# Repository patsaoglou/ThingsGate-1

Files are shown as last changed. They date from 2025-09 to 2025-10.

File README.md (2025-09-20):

#   ThingsGate-1

Gateway Motherboard powered by the ThingsCore-1 SOM. Featuring a LTE Modem, a LoraWAN Concentrator, PoE, battery power and solar charging, it is capable of supporting off-grid IoT applications.

#   Realistic View (Comming Soon...)

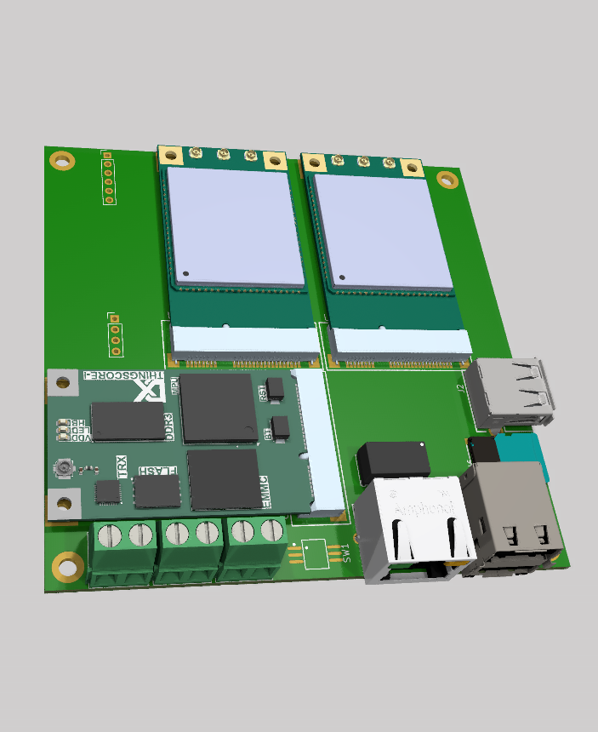
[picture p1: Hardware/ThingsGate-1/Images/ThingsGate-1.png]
Diagram


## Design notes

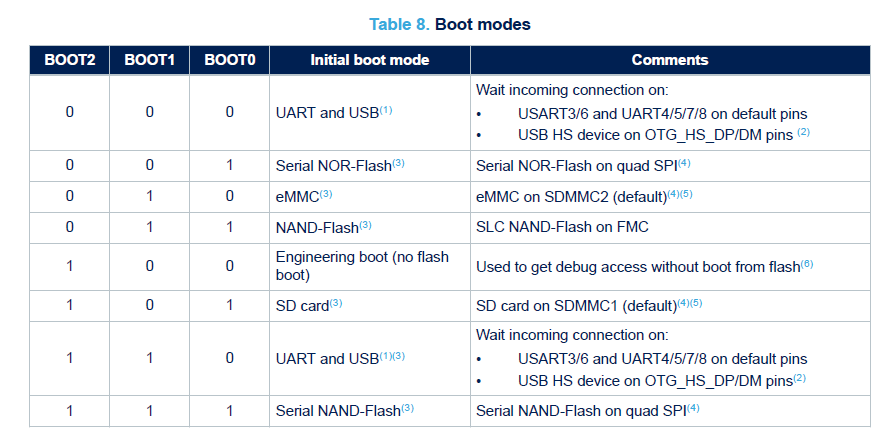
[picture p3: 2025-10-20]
Documentation/BOOTSELECTION .PNG

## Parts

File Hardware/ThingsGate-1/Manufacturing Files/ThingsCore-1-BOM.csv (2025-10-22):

Reference | Qty | Value | DNP | Footprint
BT1 | 1 | S8411-45R |  | ThingsGate-1:Battery_Holder_CR1220_S8411-45R
C1,C2,C3,C4,C5,C6,C13,C20,C21,C24,C25,C26,C32,C36,C38,C39,C40,C41,C42,C43,C44,C45,C49,C52,C54 | 25 | 100n |  | Capacitor_SMD:C_0603_1608Metric
C7 | 1 | 1n |  | Capacitor_SMD:C_1206_3216Metric
C8,C31,C51,C58 | 4 | 10u |  | Fuse:Fuse_0805_2012Metric
C9,C10 | 2 | 330uF 50V |  | Capacitor_SMD:CP_Elec_10x10.5
C11,C12 | 2 | 10u |  | Capacitor_SMD:C_0805_2012Metric
C14,C15 | 2 | 47u |  | Capacitor_SMD:C_0805_2012Metric
C16 | 1 | 1n |  | Capacitor_SMD:C_0603_1608Metric
C17 | 1 | 47p |  | Capacitor_SMD:C_0603_1608Metric
C18,C19,C22,C23 | 4 | 4.7u |  | Capacitor_SMD:C_0805_2012Metric
C27 | 1 | 4.7n |  | Capacitor_SMD:C_0603_1608Metric
C28,C55,C56,C57 | 4 | 39p |  | Capacitor_SMD:C_0603_1608Metric
C29,C30,C46,C47,C48 | 5 | 22u |  | Capacitor_SMD:C_0805_2012Metric
C33,C35,C37,C50,C53 | 5 | 1u |  | Fuse:Fuse_0805_2012Metric
C34 | 1 | 4.7u |  | Fuse:Fuse_0805_2012Metric
D1,D2 | 2 | B360 |  | Diode_SMD:D_SMA
D3,D5,D7 | 3 | SMAJ15CA |  | Diode_SMD:D_SMA
D4,D6 | 2 | BZT52C10 |  | Diode_SMD:D_SOD-123
D8,D9,D10,D11 | 4 | 1N5817WS |  | Diode_SMD:D_SOD-323
D12 | 1 | RED |  | LED_SMD:LED_0603_1608Metric
F1,F2,F3,F4 | 4 | 4A |  | Fuse:Fuse_1206_3216Metric
F5,F6,F7 | 3 | 500mA |  | Fuse:Fuse_1206_3216Metric
J1 | 1 | Conn_02x07_Odd_Even |  | Connector_IDC:IDC-Header_2x07_P2.54mm_Vertical
J3,J4,J6 | 3 | 691313710002 |  | ThingsGate-1:691313710002
J5 | 1 | USB_A_Stacked |  | ThingsGate-1:DUAL_USB-TYPE_A
J7 | 1 | USB_A |  | ThingsGate-1:USB-A-TH_AF-ZJB13.7
L1,L2,L3 | 3 | 6.8u |  | ThingsGate-1:L_0730-6R8M
L4 | 1 | 2.2u |  | ThingsGate-1:L_0805_2016
Q1,Q3 | 2 | Si4435DDY |  | ThingsGate-1:SO-8_3.9x4.9mm_P1.27mm
Q2,Q4,Q5,Q6,Q7 | 5 | Si4178DY |  | ThingsGate-1:SO-8_3.9x4.9mm_P1.27mm
R1,R2,R32,R34,R35,R36,R38,R40 | 8 | 100K |  | Resistor_SMD:R_0603_1608Metric
R3,R4,R5,R6 | 4 | 75R |  | Resistor_SMD:R_0603_1608Metric
R7,R8,R9,R17,R25,R26,R30,R39,R41,R42,R43,R44,R46,R47,R49,R50,R51,R52,R55,R56,R57,R58 | 22 | 10k |  | Resistor_SMD:R_0603_1608Metric
R10 | 1 | 3.24k |  | Resistor_SMD:R_0603_1608Metric
R11 | 1 | 29.4k |  | Resistor_SMD:R_0603_1608Metric
R12,R14 | 2 | 332k |  | Resistor_SMD:R_0603_1608Metric
R13,R15 | 2 | 68.1k |  | Resistor_SMD:R_0603_1608Metric
R16 | 1 | 49.4k |  | Resistor_SMD:R_0603_1608Metric
R18 | 1 | 1.91k |  | Resistor_SMD:R_0603_1608Metric
R19 | 1 | 10R |  | Resistor_SMD:R_1206_3216Metric
R20,R31 | 2 | 0.015R |  | Resistor_SMD:R_1206_3216Metric
R23,R27 | 2 | 100k |  | Resistor_SMD:R_0603_1608Metric
R24 | 1 | 7.15k |  | Resistor_SMD:R_0603_1608Metric
R28 | 1 | 2k |  | Resistor_SMD:R_0603_1608Metric
R29 | 1 | 16k |  | Resistor_SMD:R_0603_1608Metric
R33 | 1 | 5.1K |  | Resistor_SMD:R_0603_1608Metric
R37 | 1 | 10K |  | Resistor_SMD:R_0603_1608Metric
R45 | 1 | 100R |  | Resistor_SMD:R_0603_1608Metric
SW1 | 1 | DSHP03TS-S |  | ThingsGate-1:SW-SMD_DSHP03TS-S
T1 | 1 | H1102NL |  | ThingsGate-1:H1102NL
TP1,TP2,TP3,TP4,TP5,TP6,TP7,TP8 | 8 | TestPoint |  | TestPoint:TestPoint_Pad_D1.5mm
U1 | 1 | CH334R |  | Package_SO:QSOP-16_3.9x4.9mm_P0.635mm
U2 | 1 | ThingsCore-1 |  | ThingsGate-1:ThingsCore-1
U3 | 1 | POE_PD_Module |  | ThingsGate-1:SDAPO_DP9700
U4,U12,U13 | 3 | LM74700 |  | Package_TO_SOT_SMD:SOT-23-6
U5 | 1 | BQ24650 |  | ThingsGate-1:Texas_RVA_VQFN-16-1EP_3.5x3.5mm_P0.5mm_EP2.14x2.14mm_ThermalVias
U6 | 1 | TCA9535PWR |  | Package_SO:SSOP-24_5.3x8.2mm_P0.65mm
U7,U8 | 2 | mPCIE-52P-SLOT |  | ThingsGate-1:mpcie-slot_full
U9,U10 | 2 | TPS54331DR |  | ThingsGate-1:TPS54331DDAR_PowerPAD
U11 | 1 | RJ45-202-007-02 |  | ThingsGate-1:RJ45-TH_RJ45-202-007-02
U14 | 1 | LM324 |  | Package_SO:SOIC-14_3.9x8.7mm_P1.27mm
U15 | 1 | TF-123B-ARP9H17 |  | ThingsGate-1:TF-SMD_TF-123-ARP9H15
U16 | 1 | SMN-305-ARP7 |  | ThingsGate-1:NANO-SIM-SMD_SMN-305-ARP7
U17,U18 | 2 | PC817 |  | Package_DIP:DIP-4_W7.62mm_SMDSocket_SmallPads
Y1 | 1 | X322512MOB4SI |  | Crystal:Crystal_SMD_3225-4Pin_3.2x2.5mm

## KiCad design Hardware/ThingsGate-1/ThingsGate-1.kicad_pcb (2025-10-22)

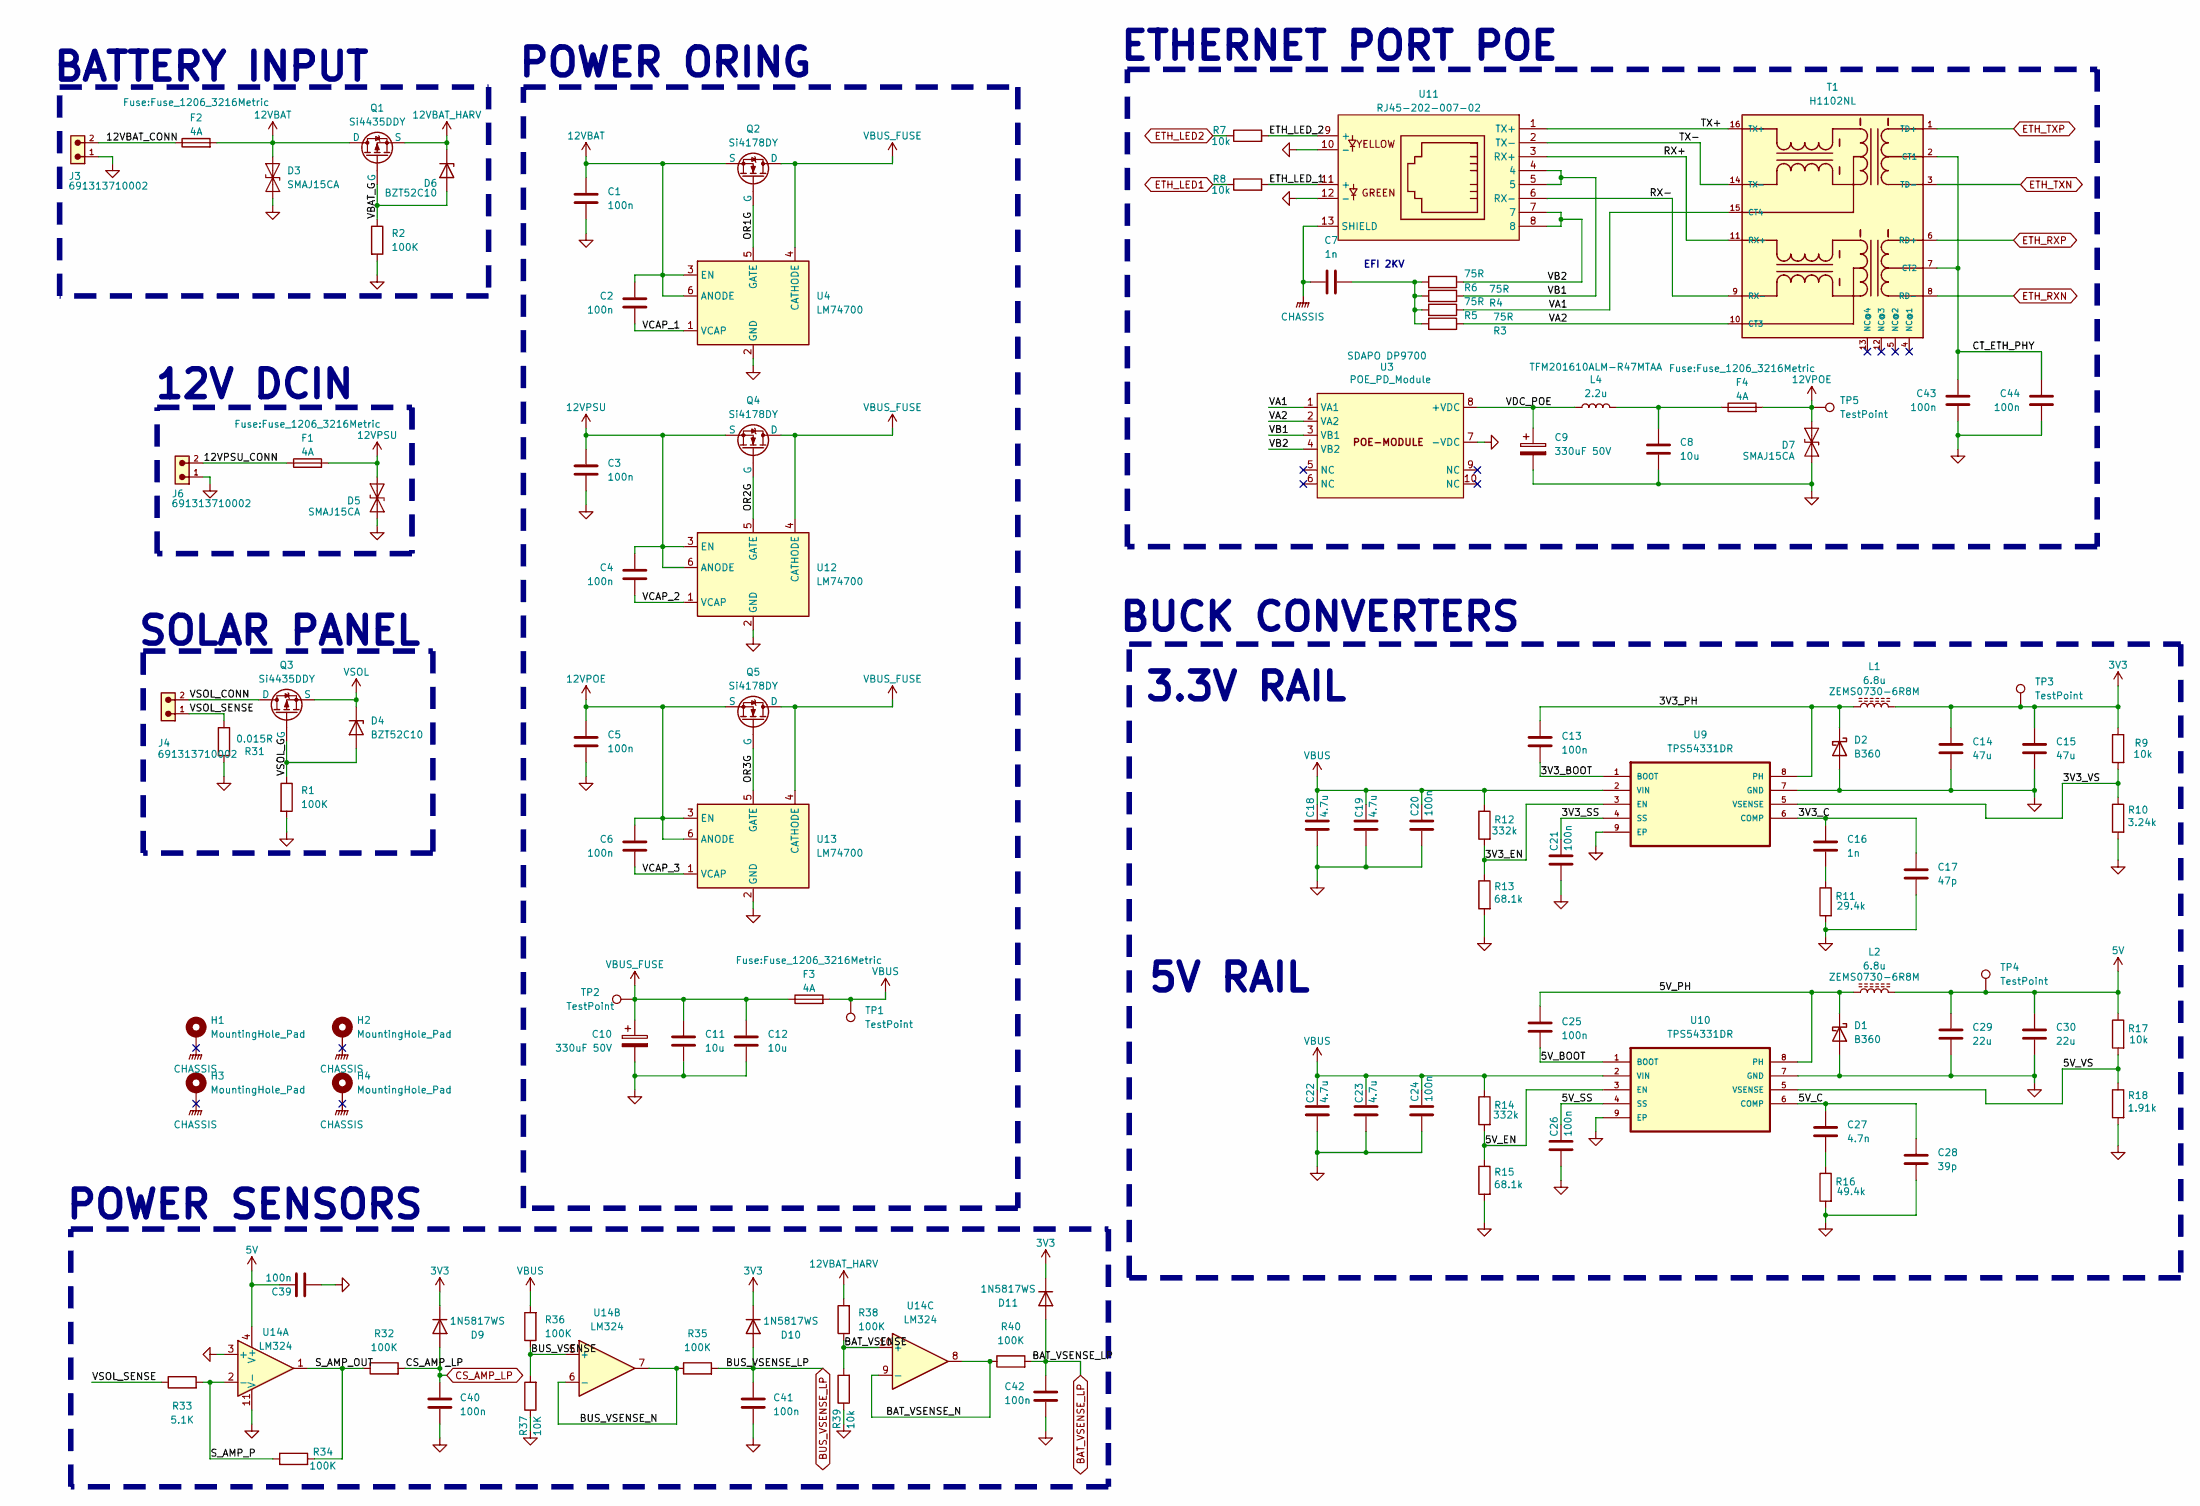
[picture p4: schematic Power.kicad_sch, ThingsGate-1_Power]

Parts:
C1, C2, C3, C4, C5, C6, C13, C20, C21, C24, C25, C26, C39, C40, C41, C42, C43, C44: 100n; C_0603_1608Metric
C7: 1n; C_1206_3216Metric
C8: 10u; Fuse_0805_2012Metric
C9, C10: 330uF 50V; CP_Elec_10x10.5
C11, C12: 10u; C_0805_2012Metric
C14, C15: 47u; C_0805_2012Metric
C16: 1n; C_0603_1608Metric
C17: 47p; C_0603_1608Metric
C18, C19, C22, C23: 4.7u; C_0805_2012Metric
C27: 4.7n; C_0603_1608Metric
C28: 39p; C_0603_1608Metric
C29, C30: 22u; C_0805_2012Metric
D1, D2: B360; D_SMA
D3, D5, D7: SMAJ15CA; D_SMA
D4, D6: BZT52C10; D_SOD-123
D9, D10, D11: 1N5817WS; D_SOD-323
F1, F2, F3, F4: 4A; Fuse_1206_3216Metric
H1, H2, H3, H4: MountingHole_Pad; MountingHole_3.2mm_M3_DIN965_Pad_TopBottom
J3, J4, J6: 691313710002
L1, L2: 6.8u; L_0730-6R8M
L4: 2.2u; L_0805_2016
Q1, Q3: Si4435DDY; SO-8_3.9x4.9mm_P1.27mm
Q2, Q4, Q5: Si4178DY; SO-8_3.9x4.9mm_P1.27mm
R1, R2, R32, R34, R35, R36, R38, R40: 100K; R_0603_1608Metric
R3, R4, R5, R6: 75R; R_0603_1608Metric
R7, R8, R9, R17, R39: 10k; R_0603_1608Metric
R10: 3.24k; R_0603_1608Metric
R11: 29.4k; R_0603_1608Metric
R12, R14: 332k; R_0603_1608Metric
R13, R15: 68.1k; R_0603_1608Metric
R16: 49.4k; R_0603_1608Metric
R18: 1.91k; R_0603_1608Metric
R31: 0.015R; R_1206_3216Metric
R33: 5.1K; R_0603_1608Metric
R37: 10K; R_0603_1608Metric
T1: H1102NL
TP1, TP2, TP3, TP4, TP5: TestPoint; TestPoint_Pad_D1.5mm
U3: POE_PD_Module; SDAPO_DP9700; Part SDAPO DP9700
U4, U12, U13: LM74700; SOT-23-6
U9, U10: TPS54331DR; TPS54331DDAR_PowerPAD
U11: RJ45-202-007-02; RJ45-TH_RJ45-202-007-02
U14: LM324; SOIC-14_3.9x8.7mm_P1.27mm

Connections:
3V3: C14.1, C15.1, D9.1 (K), D10.1 (K), D11.1 (K), L1.2, R9.1, TP3.1; also elsewhere on the board
5V: C29.1, C30.1, C39.1, L2.2, R17.1, TP4.1, U14.4 (V+); also elsewhere on the board
12VBAT: C1.1, C2.1, D3.2 (A2), F2.2, Q1.5 (D), Q1.6 (D), Q1.7 (D), Q1.8 (D), Q2.1 (S), Q2.2 (S), Q2.3 (S), U4.3 (EN), U4.6 (ANODE)
12VBAT_HARV: D6.1 (K), Q1.1 (S), Q1.2 (S), Q1.3 (S), R38.2; also elsewhere on the board
12VPOE: C5.1, C6.1, D7.2 (A2), F4.2, Q5.1 (S), Q5.2 (S), Q5.3 (S), TP5.1, U13.3 (EN), U13.6 (ANODE)
12VPSU: C3.1, C4.1, D5.2 (A2), F1.2, Q4.1 (S), Q4.2 (S), Q4.3 (S), U12.3 (EN), U12.6 (ANODE)
/Power Supply/3V3_BOOT: C13.2, U9.1 (BOOT)
/Power Supply/3V3_C: C16.1, C17.1, U9.6 (COMP)
/Power Supply/3V3_EN: R12.2, R13.1, U9.3 (EN)
/Power Supply/3V3_PH: C13.1, D2.1 (K), L1.1, U9.8 (PH)
/Power Supply/3V3_SS: C21.1, U9.4 (SS)
/Power Supply/3V3_VS: R9.2, R10.1, U9.5 (VSENSE)
/Power Supply/5V_BOOT: C25.2, U10.1 (BOOT)
/Power Supply/5V_C: C27.1, C28.1, U10.6 (COMP)
/Power Supply/5V_EN: R14.2, R15.1, U10.3 (EN)
/Power Supply/5V_PH: C25.1, D1.1 (K), L2.1, U10.8 (PH)
/Power Supply/5V_SS: C26.1, U10.4 (SS)
/Power Supply/5V_VS: R17.2, R18.1, U10.5 (VSENSE)
/Power Supply/12VBAT_CONN: F2.1, J3.2
/Power Supply/12VPSU_CONN: F1.1, J6.2
/Power Supply/BAT_VSENSE: R38.1, R39.2, U14.10 (+)
/Power Supply/BAT_VSENSE_N: R40.1, U14.8, U14.9 (-)
/Power Supply/BUS_VSENSE: R36.1, R37.2, U14.5 (+)
/Power Supply/BUS_VSENSE_N: R35.1, U14.6 (-), U14.7
/Power Supply/CT_ETH_PHY: C43.1, C44.1, T1.2 (CT1), T1.7 (CT2)
/Power Supply/ETH_LED_1: R8.2, U11.11 (+)
/Power Supply/ETH_LED_2: R7.2, U11.9 (+)
/Power Supply/OR1G: Q2.4 (G), U4.5 (GATE)
/Power Supply/OR2G: Q4.4 (G), U12.5 (GATE)
/Power Supply/OR3G: Q5.4 (G), U13.5 (GATE)
/Power Supply/RX+: T1.11 (RX+), U11.3 (RX+)
/Power Supply/RX-: T1.9 (RX-), U11.6 (RX-)
/Power Supply/S_AMP_OUT: R32.1, R34.2, U14.1
/Power Supply/S_AMP_P: R33.2, R34.1, U14.2 (-)
/Power Supply/TX+: T1.16 (TX+), U11.1 (TX+)
/Power Supply/TX-: T1.14 (TX-), U11.2 (TX-)
/Power Supply/VA1: R5.1, T1.15 (CT4), U3.1 (VA1)
/Power Supply/VA2: R3.1, T1.10 (CT3), U3.2 (VA2)
/Power Supply/VB1: R4.1, U3.3 (VB1), U11.4, U11.5
/Power Supply/VB2: R6.1, U3.4 (VB2), U11.7, U11.8
/Power Supply/VBAT_G: D6.2 (A), Q1.4 (G), R2.1
/Power Supply/VCAP_1: C2.2, U4.1 (VCAP)
/Power Supply/VCAP_2: C4.2, U12.1 (VCAP)
/Power Supply/VCAP_3: C6.2, U13.1 (VCAP)
/Power Supply/VDC_POE: C9.1, L4.1, U3.8 (+VDC)
/Power Supply/VSOL_CONN: J4.2, Q3.5 (D), Q3.6 (D), Q3.7 (D), Q3.8 (D)
/Power Supply/VSOL_G: D4.2 (A), Q3.4 (G), R1.1
/Power Supply/VSOL_SENSE: J4.1, R31.1, R33.1
BAT_VSENSE_LP: C42.2, D11.2 (A), R40.2; also elsewhere on the board
BUS_VSENSE_LP: C41.2, D10.2 (A), R35.2; also elsewhere on the board
CHASSIS: C7.1, H1.1, H2.1, H3.1, H4.1, U11.13 (SHIELD); also elsewhere on the board
CS_AMP_LP: C40.2, D9.2 (A), R32.2; also elsewhere on the board
ETH_LED1: R8.1; also elsewhere on the board
ETH_LED2: R7.1; also elsewhere on the board
ETH_RXN: T1.8 (RD-); also elsewhere on the board
ETH_RXP: T1.6 (RD+); also elsewhere on the board
ETH_TXN: T1.3 (TD-); also elsewhere on the board
ETH_TXP: T1.1 (TD+); also elsewhere on the board
GND: C1.2, C3.2, C5.2, C8.2, C9.2, C10.2, C11.2, C12.2, C14.2, C15.2, C17.2, C18.2, C19.2, C20.2, C21.2, C22.2, C23.2, C24.2, C26.2, C28.2, C29.2, C30.2, C39.2, C40.1, C41.1, C42.1, C43.2, C44.2, D1.2 (A), D2.2 (A), D3.1 (A1), D5.1 (A1), D7.1 (A1), J3.1, J6.1, R1.2, R2.2, R10.2, R11.2, R13.2, R15.2, R16.2, R18.2, R31.2, R37.1, R39.1, U3.7 (-VDC), U4.2 (GND), U9.7 (GND), U9.9 (EP), U10.7 (GND), U10.9 (EP), U11.10 (-), U11.12 (-), U12.2 (GND), U13.2 (GND), U14.3 (+), U14.11 (V-); also elsewhere on the board
unnamed: C7.2, R3.2, R4.2, R5.2, R6.2
unnamed: C8.1, F4.1, L4.2
unnamed: C16.2, R11.1
unnamed: C27.2, R16.1
VBUS: C18.1, C19.1, C20.1, C22.1, C23.1, C24.1, F3.2, R12.1, R14.1, R36.2, TP1.1, U9.2 (VIN), U10.2 (VIN)
VBUS_FUSE: C10.1, C11.1, C12.1, F3.1, Q2.5 (D), Q2.6 (D), Q2.7 (D), Q2.8 (D), Q4.5 (D), Q4.6 (D), Q4.7 (D), Q4.8 (D), Q5.5 (D), Q5.6 (D), Q5.7 (D), Q5.8 (D), TP2.1, U4.4 (CATHODE), U12.4 (CATHODE), U13.4 (CATHODE)
VSOL: D4.1 (K), Q3.1 (S), Q3.2 (S), Q3.3 (S); also elsewhere on the board

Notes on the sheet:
BUCK CONVERTERS
ETHERNET PORT POE
BATTERY INPUT
3.3V RAIL
POWER SENSORS
5V RAIL
SOLAR PANEL
EFI 2KV
12V DCIN
POWER ORING

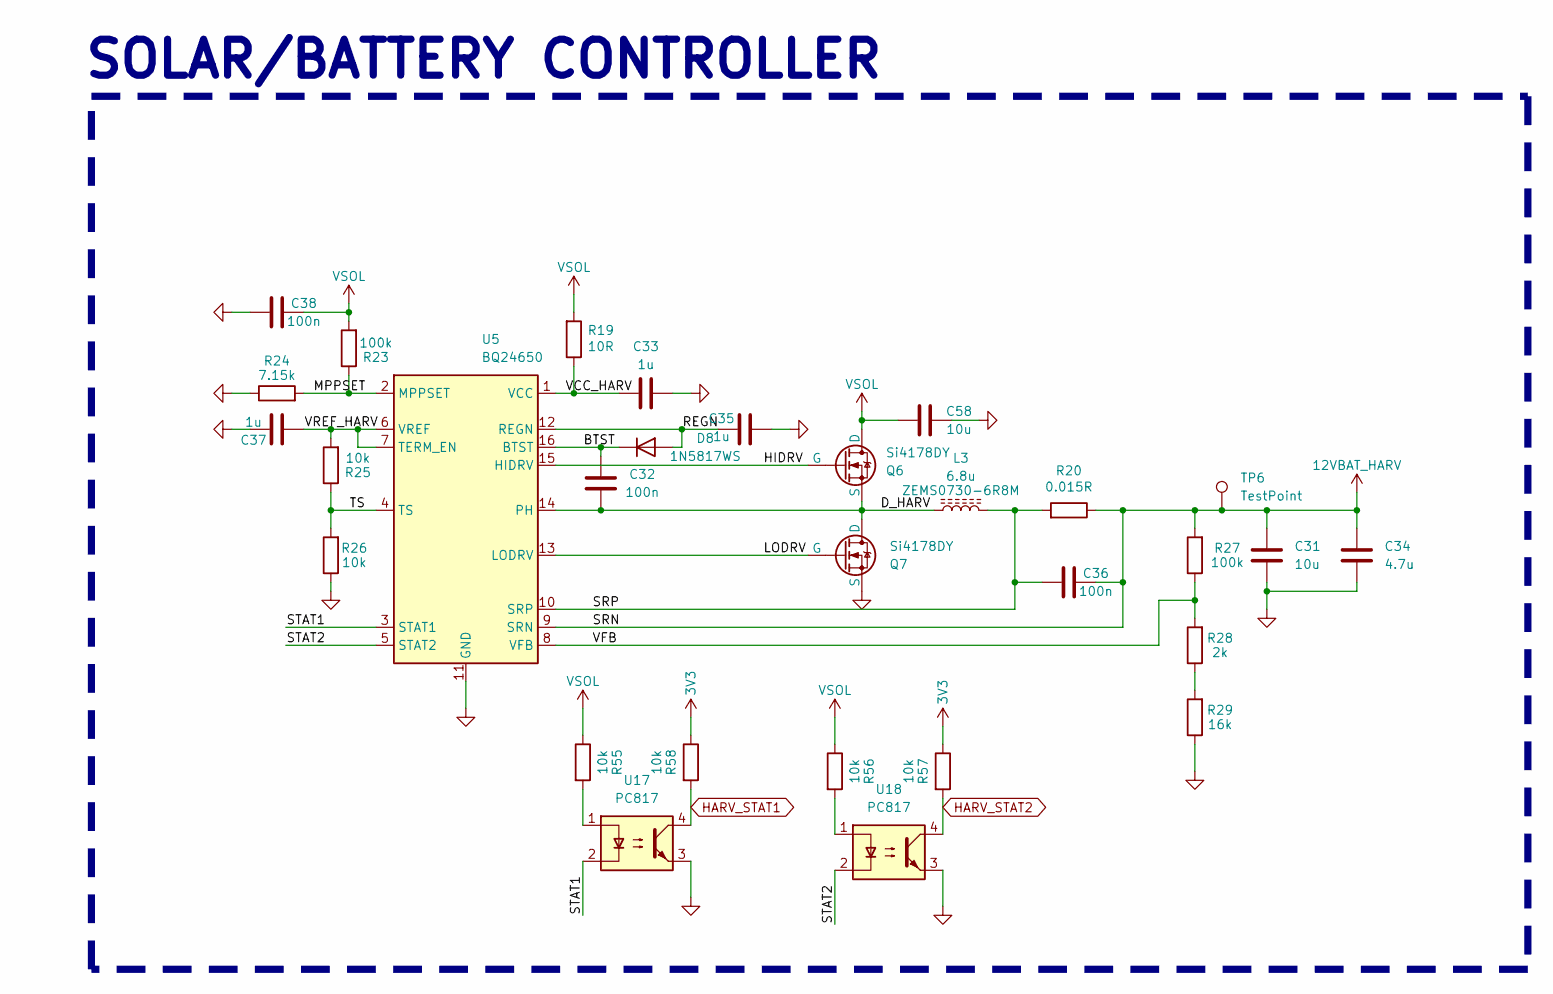
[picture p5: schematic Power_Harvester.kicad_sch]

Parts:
C31, C58: 10u; Fuse_0805_2012Metric
C32, C36, C38: 100n; C_0603_1608Metric
C33, C35, C37: 1u; Fuse_0805_2012Metric
C34: 4.7u; Fuse_0805_2012Metric
D8: 1N5817WS; D_SOD-323
L3: 6.8u; L_0730-6R8M
Q6, Q7: Si4178DY; SO-8_3.9x4.9mm_P1.27mm
R19: 10R; R_1206_3216Metric
R20: 0.015R; R_1206_3216Metric
R23, R27: 100k; R_0603_1608Metric
R24: 7.15k; R_0603_1608Metric
R25, R26, R55, R56, R57, R58: 10k; R_0603_1608Metric
R28: 2k; R_0603_1608Metric
R29: 16k; R_0603_1608Metric
TP6: TestPoint; TestPoint_Pad_D1.5mm
U5: BQ24650; Texas_RVA_VQFN-16-1EP_3.5x3.5mm_P0.5mm_EP2.14x2.14mm_Therma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
U17, U18: PC817; DIP-4_W7.62mm_SMDSocket_SmallPads

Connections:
3V3: R57.1, R58.1; also elsewhere on the board
12VBAT_HARV: C31.1, C34.1, C36.2, R20.1, R27.2, TP6.1, U5.9 (SRN); also elsewhere on the board
/Power Harvester/BTST: C32.1, D8.1 (K), U5.16 (BTST)
/Power Harvester/D_HARV: C32.2, L3.1, Q6.1 (S), Q6.2 (S), Q6.3 (S), Q7.5 (D), Q7.6 (D), Q7.7 (D), Q7.8 (D), U5.14 (PH)
/Power Harvester/HIDRV: Q6.4 (G), U5.15 (HIDRV)
/Power Harvester/LODRV: Q7.4 (G), U5.13 (LODRV)
/Power Harvester/MPPSET: R23.1, R24.2, U5.2 (MPPSET)
/Power Harvester/REGN: C35.2, D8.2 (A), U5.12 (REGN)
/Power Harvester/SRP: C36.1, L3.2, R20.2, U5.10 (SRP)
/Power Harvester/STAT1: U5.3 (STAT1), U17.2
/Power Harvester/STAT2: U5.5 (STAT2), U18.2
/Power Harvester/TS: R25.1, R26.2, U5.4 (TS)
/Power Harvester/VCC_HARV: C33.1, R19.1, U5.1 (VCC)
/Power Harvester/VFB: R27.1, R28.2, U5.8 (VFB)
/Power Harvester/VREF_HARV: C37.1, R25.2, U5.6 (VREF), U5.7 (TERM_EN)
GND: C31.2, C33.2, C34.2, C35.1, C37.2, C38.1, C58.2, Q7.1 (S), Q7.2 (S), Q7.3 (S), R24.1, R26.1, R29.1, U5.11 (GND), U5.17 (GND), U17.3, U18.3; also elsewhere on the board
HARV_STAT1: R58.2, U17.4; also elsewhere on the board
HARV_STAT2: R57.2, U18.4; also elsewhere on the board
unnamed: R28.1, R29.2
unnamed: R55.2, U17.1
unnamed: R56.2, U18.1
VSOL: C38.2, C58.1, Q6.5 (D), Q6.6 (D), Q6.7 (D), Q6.8 (D), R19.2, R23.2, R55.1, R56.1; also elsewhere on the board

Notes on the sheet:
SOLAR/BATTERY CONTROLLER

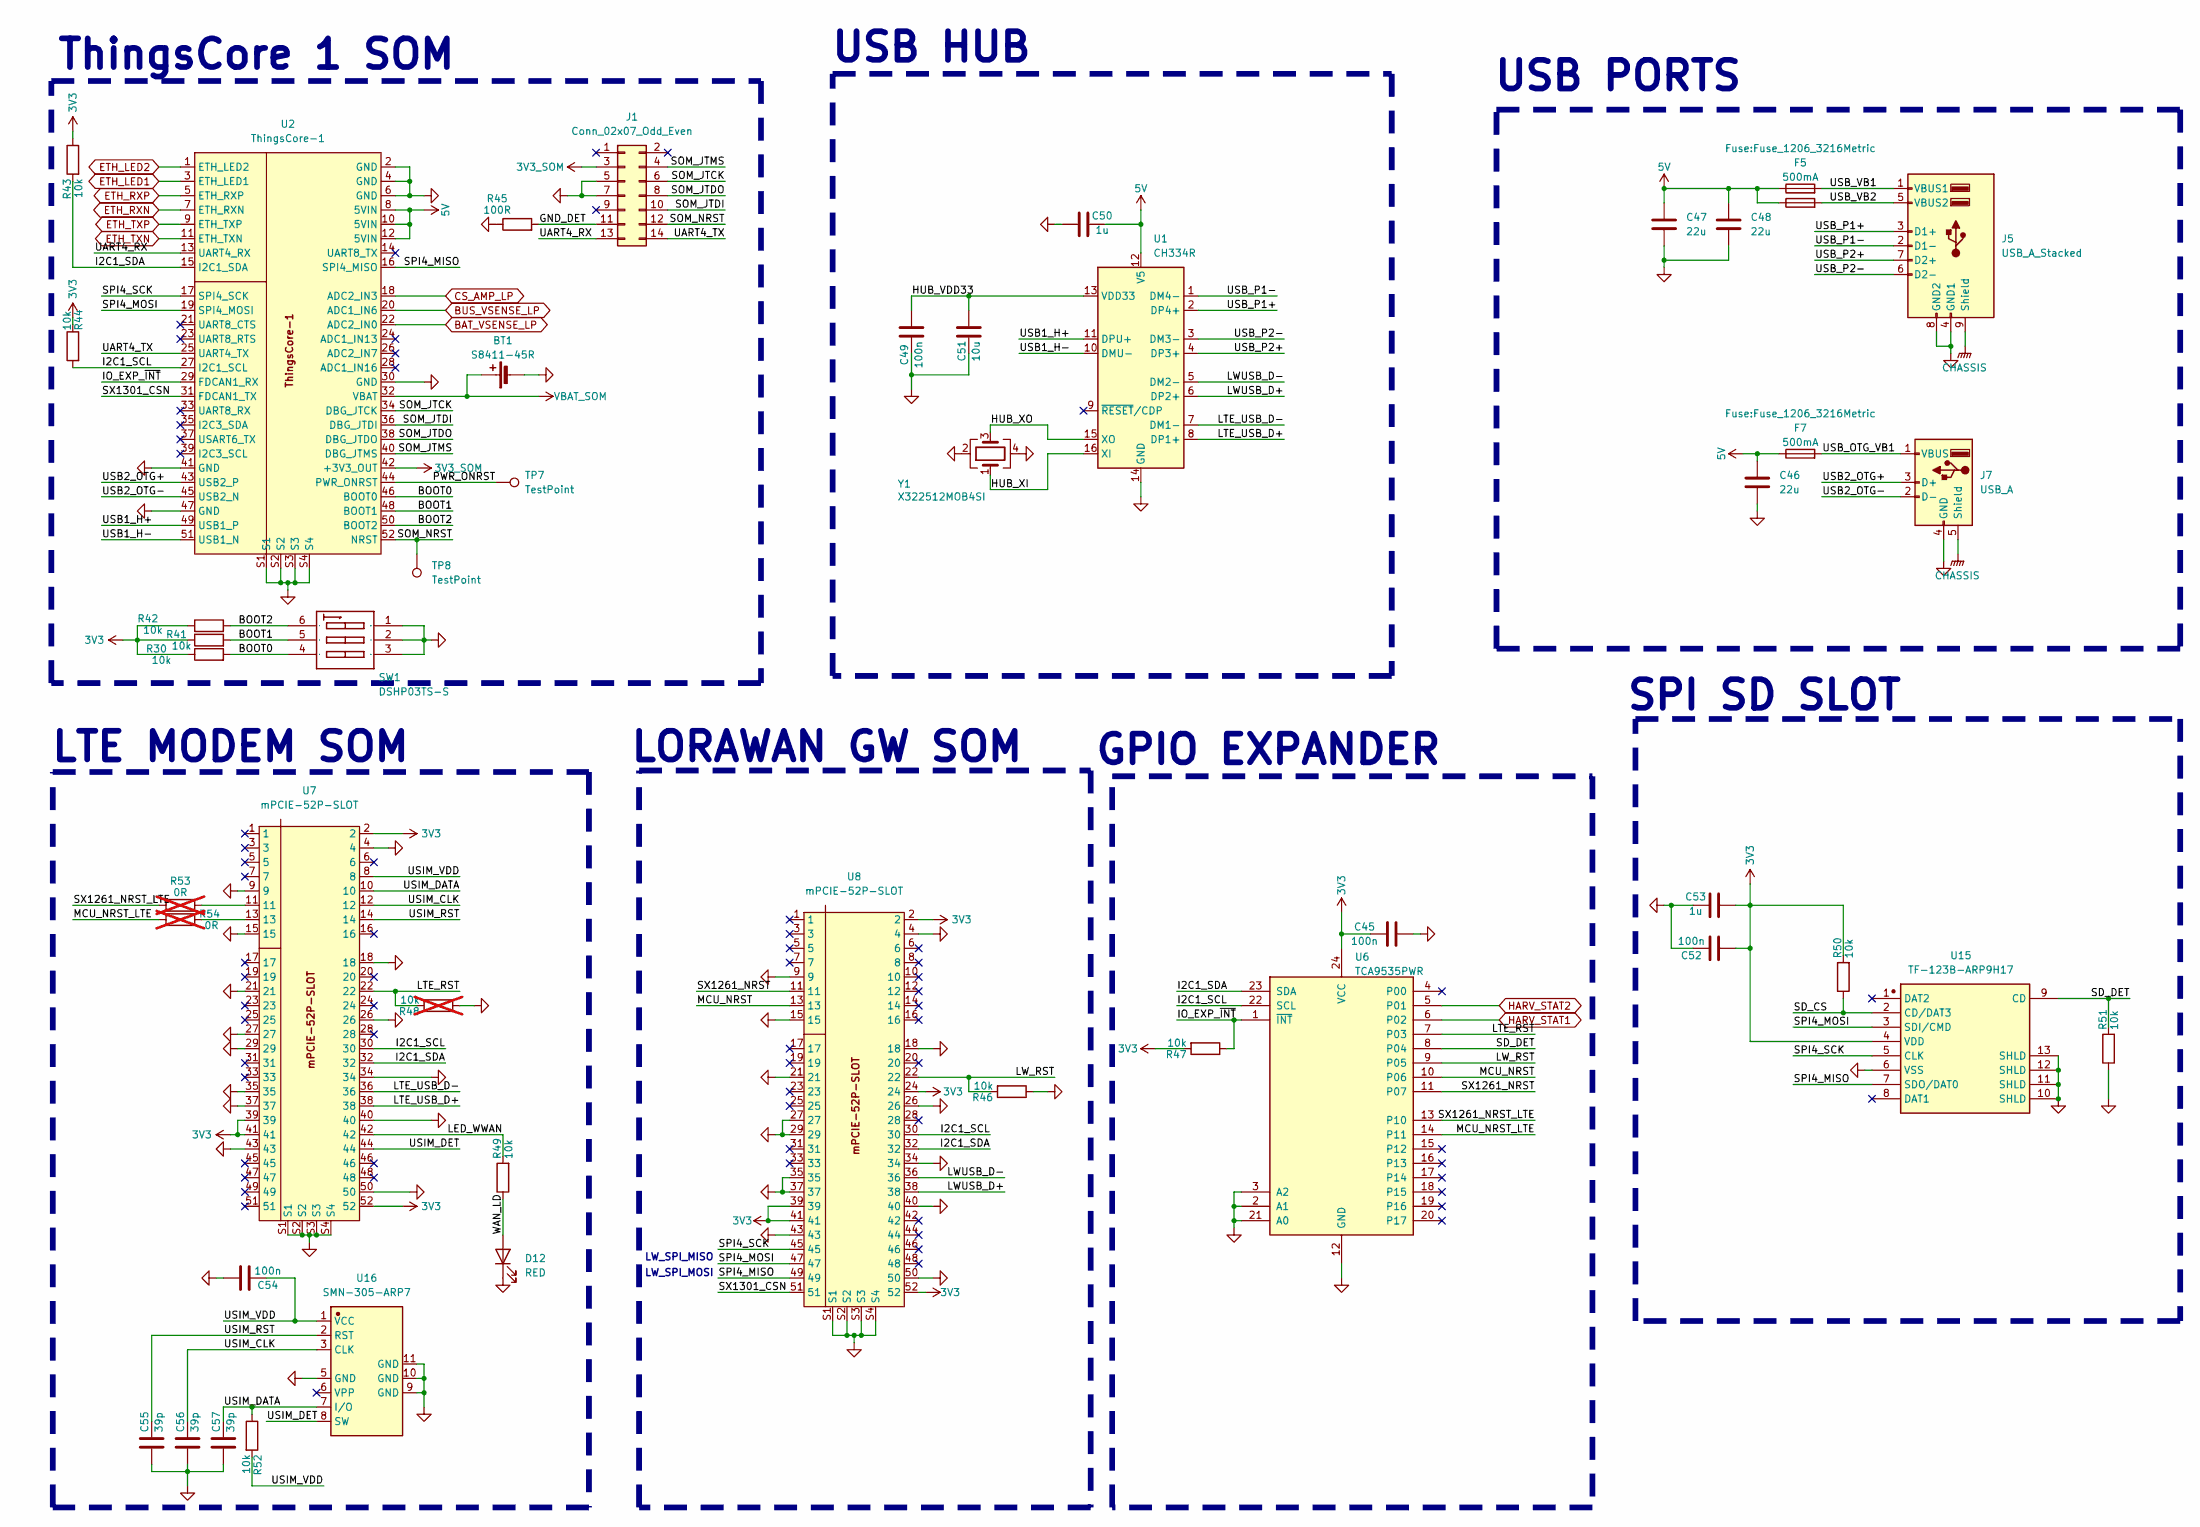
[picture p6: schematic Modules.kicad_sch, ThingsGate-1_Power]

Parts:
BT1: S8411-45R; Battery_Holder_CR1220_S8411-45R
C45, C49, C52, C54: 100n; C_0603_1608Metric
C46, C47, C48: 22u; C_0805_2012Metric
C50, C53: 1u; Fuse_0805_2012Metric
C51: 10u; Fuse_0805_2012Metric
C55, C56, C57: 39p; C_0603_1608Metric
D12: RED; LED_0603_1608Metric
F5, F6, F7: 500mA; Fuse_1206_3216Metric
J1: Conn_02x07_Odd_Even; IDC-Header_2x07_P2.54mm_Vertical
J5: USB_A_Stacked; DUAL_USB-TYPE_A
J7: USB_A; USB-A-TH_AF-ZJB13.7
R30, R41, R42, R43, R44, R46, R47, R49, R50, R51, R52: 10k; R_0603_1608Metric
R45: 100R; R_0603_1608Metric
R48: 10k; R_0603_1608Metric; not fitted
R53, R54: 0R; R_0603_1608Metric; not fitted
SW1: DSHP03TS-S; SW-SMD_DSHP03TS-S
TP7, TP8: TestPoint; TestPoint_Pad_D1.5mm
U1: CH334R; QSOP-16_3.9x4.9mm_P0.635mm
U2: ThingsCore-1
U6: TCA9535PWR; SSOP-24_5.3x8.2mm_P0.65mm
U7, U8: mPCIE-52P-SLOT; mpcie-slot_full
U15: TF-123B-ARP9H17; TF-SMD_TF-123-ARP9H15
U16: SMN-305-ARP7; NANO-SIM-SMD_SMN-305-ARP7
Y1: X322512MOB4SI; Crystal_SMD_3225-4Pin_3.2x2.5mm

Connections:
3V3: C45.1, C52.1, C53.1, R30.1, R41.1, R42.1, R43.1, R44.1, R47.2, R50.2, U6.24 (VCC), U7.2, U7.39, U7.41, U7.52, U8.2, U8.24, U8.39, U8.41, U8.52, U15.4 (VDD); also elsewhere on the board
3V3_SOM: J1.3, U2.42 (+3V3_OUT)
5V: C46.1, C47.1, C48.1, C50.2, F5.1, F6.1, F7.1, U1.12 (V5), U2.8 (5VIN), U2.10 (5VIN), U2.12 (5VIN); also elsewhere on the board
/Modules/BOOT0: R30.2, SW1.4, U2.46 (BOOT0)
/Modules/BOOT1: R41.2, SW1.5, U2.48 (BOOT1)
/Modules/BOOT2: R42.2, SW1.6, U2.50 (BOOT2)
/Modules/GND_DET: J1.11, R45.2
/Modules/HUB_VDD33: C49.1, C51.1, U1.13 (VDD33)
/Modules/HUB_XI: U1.16 (XI), Y1.1
/Modules/HUB_XO: U1.15 (XO), Y1.3
/Modules/I2C1_SCL: R44.2, U2.27 (I2C1_SCL), U6.22 (SCL), U7.30, U8.30
/Modules/I2C1_SDA: R43.2, U2.15 (I2C1_SDA), U6.23 (SDA), U7.32, U8.32
/Modules/IO_EXP_~INT: R47.1, U2.29 (FDCAN1_RX), U6.1 (~INT)
/Modules/LED_WWAN: R49.2, U7.42
/Modules/LTE_RST: R48.2, U6.7 (P03), U7.22
/Modules/LTE_USB_D+: U1.8 (DP1+), U7.38
/Modules/LTE_USB_D-: U1.7 (DM1-), U7.36
/Modules/LWUSB_D+: U1.6 (DP2+), U8.38
/Modules/LWUSB_D-: U1.5 (DM2-), U8.36
/Modules/LW_RST: R46.2, U6.9 (P05), U8.22
/Modules/MCU_NRST: U6.10 (P06), U8.13
/Modules/MCU_NRST_LTE: R54.1, U6.14 (P11)
/Modules/PWR_ONRST: TP7.1, U2.44 (PWR_ONRST)
/Modules/SD_CS: R50.1, U15.2 (CD/DAT3)
/Modules/SD_DET: R51.2, U6.8 (P04), U15.9 (CD)
/Modules/SOM_JTCK: J1.6, U2.34 (DBG_JTCK)
/Modules/SOM_JTDI: J1.10, U2.36 (DBG_JTDI)
/Modules/SOM_JTDO: J1.8, U2.38 (DBG_JTDO)
/Modules/SOM_JTMS: J1.4, U2.40 (DBG_JTMS)
/Modules/SOM_NRST: J1.12, TP8.1, U2.52 (NRST)
/Modules/SPI4_MISO: U2.16 (SPI4_MISO), U8.49, U15.7 (SDO/DAT0)
/Modules/SPI4_MOSI: U2.19 (SPI4_MOSI), U8.47, U15.3 (SDI/CMD)
/Modules/SPI4_SCK: U2.17 (SPI4_SCK), U8.45, U15.5 (CLK)
/Modules/SX1261_NRST: U6.11 (P07), U8.11
/Modules/SX1261_NRST_LTE: R53.2, U6.13 (P10)
/Modules/SX1301_CSN: U2.31 (FDCAN1_TX), U8.51
/Modules/UART4_RX: J1.13, U2.13 (UART4_RX)
/Modules/UART4_TX: J1.14, U2.25 (UART4_TX)
/Modules/USB1_H+: U1.11 (DPU+), U2.49 (USB1_P)
/Modules/USB1_H-: U1.10 (DMU-), U2.51 (USB1_N)
/Modules/USB2_OTG+: J7.3 (D+), U2.43 (USB2_P)
/Modules/USB2_OTG-: J7.2 (D-), U2.45 (USB2_N)
/Modules/USB_OTG_VB1: F7.2, J7.1 (VBUS)
/Modules/USB_P1+: J5.3 (D1+), U1.2 (DP4+)
/Modules/USB_P1-: J5.2 (D1-), U1.1 (DM4-)
/Modules/USB_P2+: J5.7 (D2+), U1.4 (DP3+)
/Modules/USB_P2-: J5.6 (D2-), U1.3 (DM3-)
/Modules/USB_VB1: F5.2, J5.1 (VBUS1)
/Modules/USB_VB2: F6.2, J5.5 (VBUS2)
/Modules/USIM_CLK: C56.1, U7.12, U16.3 (CLK)
/Modules/USIM_DATA: C57.1, R52.1, U7.10, U16.7 (I/O)
/Modules/USIM_DET: U7.44, U16.8 (SW)
/Modules/USIM_RST: C55.1, U7.14, U16.2 (RST)
/Modules/USIM_VDD: C54.2, R52.2, U7.8, U16.1 (VCC)
/Modules/WAN_LD: D12.2 (A), R49.1
BAT_VSENSE_LP: U2.22 (ADC2_IN0); also elsewhere on the board
BUS_VSENSE_LP: U2.20 (ADC1_IN6); also elsewhere on the board
CHASSIS: J5.9 (Shield), J7.5 (Shield); also elsewhere on the board
CS_AMP_LP: U2.18 (ADC2_IN3); also elsewhere on the board
ETH_LED1: U2.3 (ETH_LED1); also elsewhere on the board
ETH_LED2: U2.1 (ETH_LED2); also elsewhere on the board
ETH_RXN: U2.7 (ETH_RXN); also elsewhere on the board
ETH_RXP: U2.5 (ETH_RXP); also elsewhere on the board
ETH_TXN: U2.11 (ETH_TXN); also elsewhere on the board
ETH_TXP: U2.9 (ETH_TXP); also elsewhere on the board
GND: BT1.2 (-), C45.2, C46.2, C47.2, C48.2, C49.2, C50.1, C51.2, C52.2, C53.2, C54.1, C55.2, C56.2, C57.2, D12.1 (K), J1.5, J1.7, J5.4 (GND1), J5.8 (GND2), J7.4 (GND), R45.1, R46.1, R48.1, R51.1, SW1.1, SW1.2, SW1.3, U1.14 (GND), U2.2 (GND), U2.4 (GND), U2.6 (GND), U2.30 (GND), U2.41 (GND), U2.47 (GND), U2.S1, U2.S2, U2.S3, U2.S4, U6.2 (A1), U6.3 (A2), U6.12 (GND), U6.21 (A0), U7.4, U7.9, U7.15, U7.18, U7.21, U7.26, U7.27, U7.29, U7.34, U7.35, U7.37, U7.40, U7.43, U7.50, U7.S1, U7.S2, U7.S3, U7.S4, U8.4, U8.9, U8.15, U8.18, U8.21, U8.26, U8.27, U8.29, U8.34, U8.35, U8.37, U8.40, U8.43, U8.50, U8.S1, U8.S2, U8.S3, U8.S4, U15.6 (VSS), U15.10 (SHLD), U15.11 (SHLD), U15.12 (SHLD), U15.13 (SHLD), U16.5 (GND), U16.9 (GND), U16.10 (GND), U16.11 (GND), Y1.2, Y1.4; also elsewhere on the board
HARV_STAT1: U6.6 (P02); also elsewhere on the board
HARV_STAT2: U6.5 (P01); also elsewhere on the board
unnamed: R53.1, U7.11
unnamed: R54.2, U7.13
VBAT_SOM: BT1.1 (+), U2.32 (VBAT)

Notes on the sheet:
LW_SPI_MISO
GPIO EXPANDER
USB HUB
LTE MODEM SOM
LORAWAN GW SOM
USB PORTS
SPI SD SLOT
ThingsCore 1 SOM
LW_SPI_MOSI

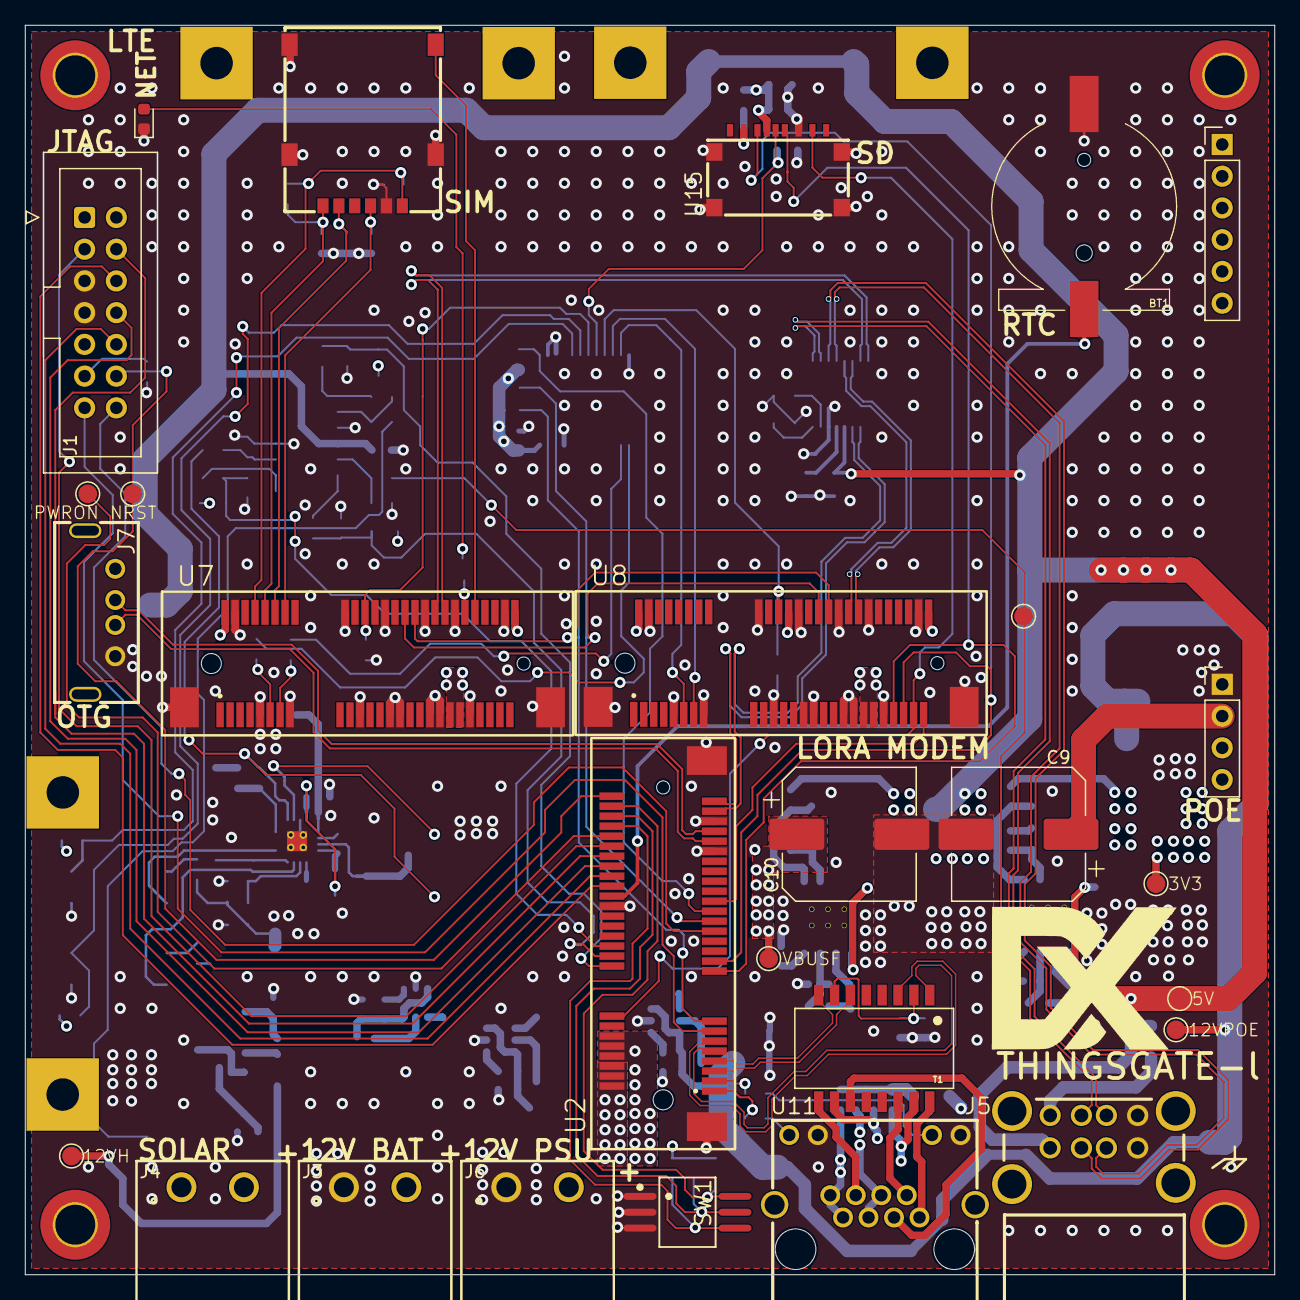
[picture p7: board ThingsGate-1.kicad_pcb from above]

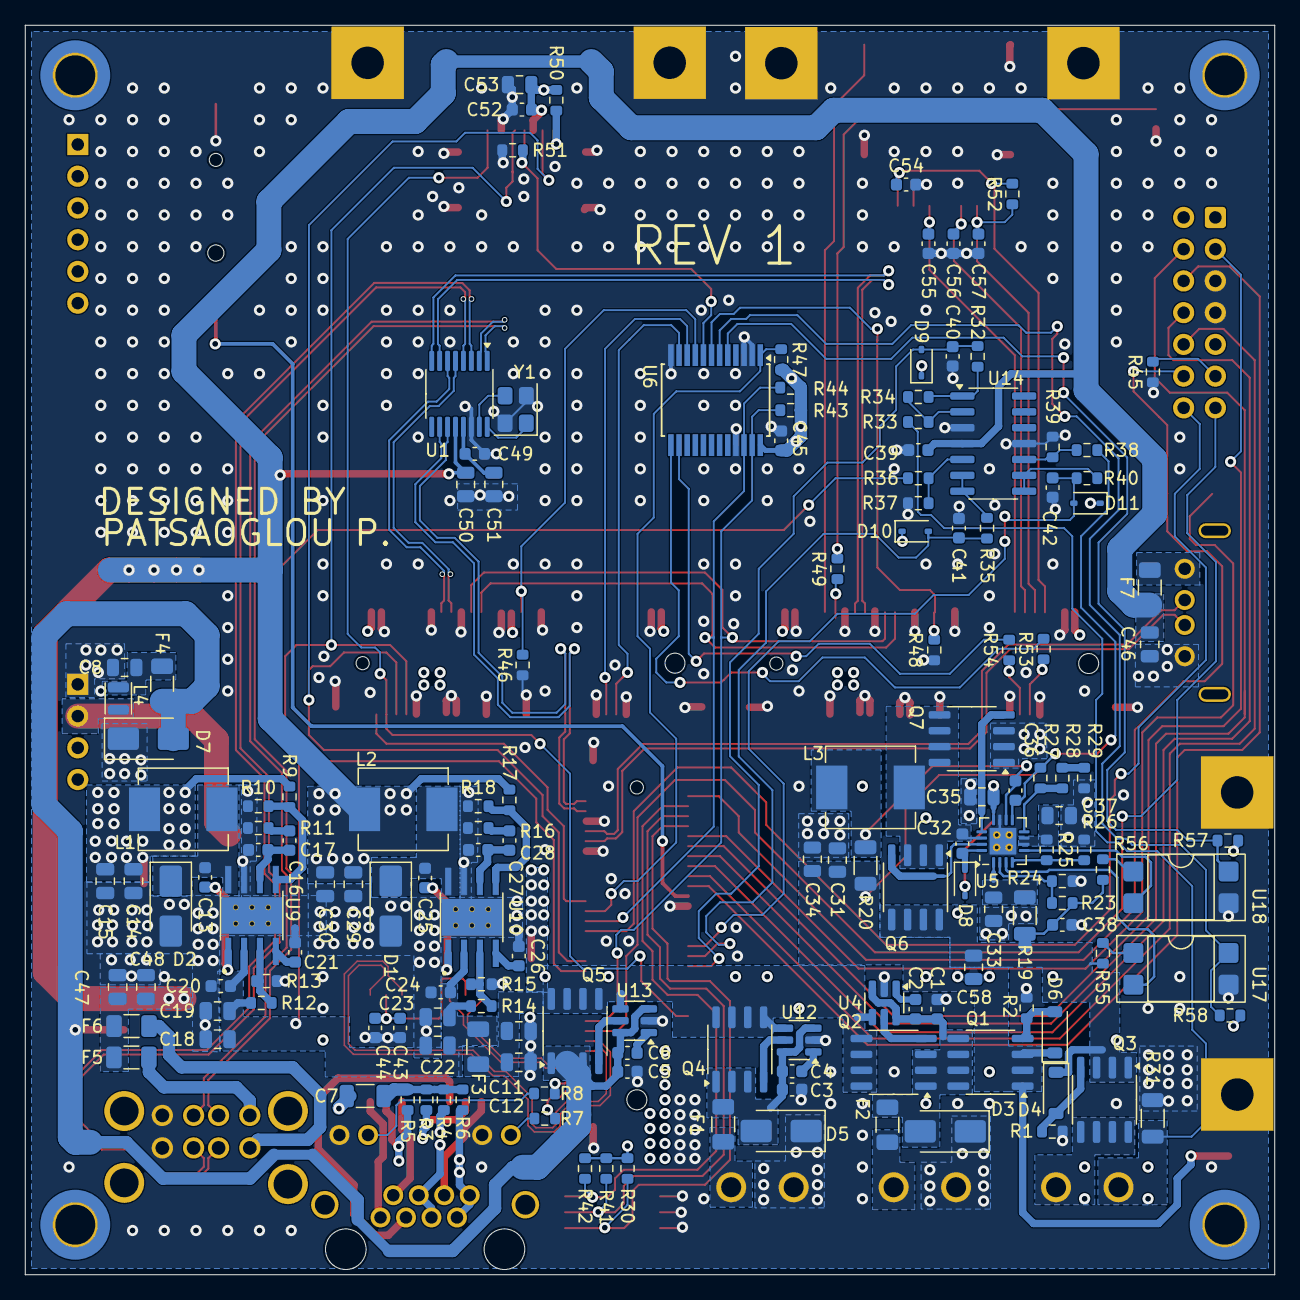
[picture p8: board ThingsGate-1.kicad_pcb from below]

Board: 4 copper layers, 100.0 x 100.0 mm, 184 parts (153 on the bottom side), 140 nets.

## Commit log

2025-10-14 harvester schematic ready
    [Modules.kicad_sch, Power.kicad_sch, Power_Harvester.kicad_sch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]
2025-10-20 mpcie wire-up
    [Modules.kicad_sch, Power.kicad_sch]
2025-10-21 placement ok
    [Modules.kicad_sch, Power.kicad_sch, Power_Harvester.kicad_sch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]
2025-10-22 layout finished. checks and fab files remaining
    [Modules.kicad_sch, Power.kicad_sch, ThingsGate-1.kicad_pcb]
2025-10-22 final fab files and checks done
    [Modules.kicad_sch, Power.kicad_sch, Power_Harvester.kicad_sch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]
